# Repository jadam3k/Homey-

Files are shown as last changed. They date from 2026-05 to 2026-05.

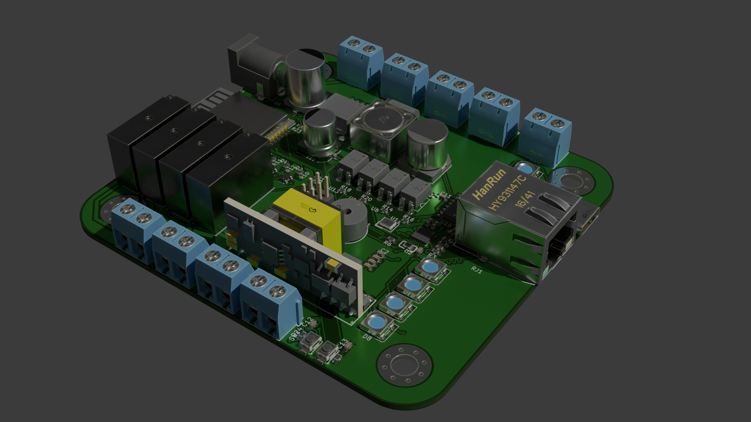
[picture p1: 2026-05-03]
Render.png

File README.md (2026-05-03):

# Homey

Homey is a compact home automation controller designed for residential use, while also being capable of operating as an industrial-style PLC for control and monitoring tasks.

The project combines Ethernet connectivity, isolated digital I/O, relay outputs, and flexible power input in a single hardware platform built around ESP32.

---

## Hardware Features

* **ESP32-based architecture** for wireless communication, local control logic, and future expansion.
* **Ethernet with PoE support** for reliable wired connectivity and simplified installation.
* **4 digital inputs** for external sensors, switches, and automation signals.
* **4 digital outputs** based on relays for switching external loads.
* **5 onboard LEDs** used for status indication, diagnostics, and visual feedback.
* **Input voltage up to 24V** for industrial and field applications.
* **5V relay section** powered separately while maintaining compatibility with higher external voltages.
* **USB-C power support** for development, testing, and low-voltage standalone operation.
* **Optocoupler isolation** allowing safe interfacing with higher voltage external circuits.

---

## Electrical Design Notes

The board is divided into functional sections.

High-voltage and switching circuitry are separated from the low-voltage logic domain in order to improve stability, reduce electrical noise, and increase operational safety.

Special attention was given to routing of high-speed and differential signals such as:

* Ethernet TX / RX
* USB D+ / D−

Component placement and routing were performed with signal integrity and practical manufacturability in mind.

---

## Firmware

The firmware has been completed and provides the basic control layer for the board.

The current software handles:

* digital input reading
* relay output control
* status LED logic
* Ethernet communication foundation

The architecture was kept clean and modular to allow future expansion for everyone - you do what you want :).

A future direction of development is communication between multiple boards using **ESP-NOW**, enabling distributed control nodes over larger areas (2/3km).

---

## Project Images

### 3D Model

Render

### Schematic



### PCB Layout / Routed Board

Zrzut ekranu 2026-05-03 140522

---

## Project Status

The project is currently considered **complete**.

Remember, if you copy it. Mention me :) i will check that.

---

## License
Just do not consider this project as your own :)

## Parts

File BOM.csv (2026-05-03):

Index | LCSC# | MPN | Manufacturer | Package | Customer # | Description | RoHS | Quantity | MOQ | Multiple | Unit Price($) | Extended Price($) | Product Link
1 | C84681 | CH340C | WCH | SOP-16 |  | Transceiver 2Mbps USB 2.0 SOP-16 Interface Controllers RoHS | yes | 2 | 1 | 1 | 0.5795 | 1.16 | https://www.lcsc.com/product-detail/C84681.html
2 | C123417 | RC0603FR-0712K1L | YAGEO | 0603 |  | 100mW 12.1kΩ 75V Thick Film Resistor ±100ppm/℃ ±1% 0603 Chip Resistor - Surface Mount RoHS | yes | 100 | 100 | 100 | 0.0017 | 0.17 | https://www.lcsc.com/product-detail/C123417.html
3 | C17181196 | B57321V2222H060 | TDK | 0603 |  | 2.2kΩ 180mW ±3% 3940K 0603 NTC Thermistors RoHS | yes | 10 | 1 | 1 | 0.0799 | 0.80 | https://www.lcsc.com/product-detail/C17181196.html
4 | C91754 | HY931147C | HANRUN(Zhongshan HanRun Elec) | Through Hole |  | Jack Modular Connector RJ45 Through Hole | yes | 2 | 1 | 1 | 2.5442 | 5.09 | https://www.lcsc.com/product-detail/C91754.html
5 | C48746 | G5NB-1A-E-DC5V | OMRON | Through Hole,20.4x7mm |  | 5V 1 Set Normally Open: 1A (SPST NO) Through Hole,20.4x7mm Power Relays RoHS | yes | 8 | 1 | 1 | 0.5668 | 4.53 | https://www.lcsc.com/product-detail/C48746.html
6 | C720477 | TS-1088-AR02016 | XUNPU | SMD,4x3mm |  | Tactile Switch SPST 160gf 2mm SMD (SMT) Tab 4mm x 3mm Surface Mount | yes | 10 | 10 | 10 | 0.0558 | 0.56 | https://www.lcsc.com/product-detail/C720477.html
7 | C701342 | ESP32-WROOM-32E-N8 | ESPRESSIF | SMD,25.5x18mm |  | 2.4GHz ESP32-DOWD-V3 On-board PCB Antenna -98dBm SMD,25.5x18mm RF Transceiver Modules and Modems RoHS | yes | 2 | 1 | 1 | 4.4175 | 8.84 | https://www.lcsc.com/product-detail/C701342.html
8 | C20612449 | PC817C | KTP | DIP-4 |  | 50mA 100mV@20mA,1mA 35V 6V 1.2V DC DIP-4 Transistor, Photovoltaic Output Optoisolators RoHS | yes | 20 | 20 | 20 | 0.0360 | 0.72 | https://www.lcsc.com/product-detail/C20612449.html
9 | C474881 | KF301-5.0-2P | Cixi Kefa Elec | Through Hole,P=5mm |  | 2 Position Wire to Board Terminal Block Through Hole 5mm | yes | 20 | 5 | 5 | 0.0919 | 1.84 | https://www.lcsc.com/product-detail/C474881.html
10 | C2907044 | FRC0603F5101TS | FOJAN | 0603 |  | 5.1kΩ ±1% 100mW 0603 Thick Film Resistor | yes | 100 | 100 | 100 | 0.0012 | 0.12 | https://www.lcsc.com/product-detail/C2907044.html
11 | C2869734 | LM66100DCKR | TI | SC-70-6 |  | 95mΩ 1 SC-70-6 OR Controllers, Ideal Diodes RoHS | yes | 10 | 5 | 5 | 0.2025 | 2.03 | https://www.lcsc.com/product-detail/C2869734.html
12 | C7471898 | 189RV0036 | KNSCHA | SMD,D10xL10.5mm |  | 680uF ±20% 35V Aluminum Electrolytic Capacitors 2000hrs@105℃ | yes | 5 | 5 | 5 | 0.2571 | 1.29 | https://www.lcsc.com/product-detail/C7471898.html
13 | C45223 | LAN8720A-CP-TR | MICROCHIP | QFN-24-EP(4x4) |  | 1.6V~3.6V PHY Transceiver RMII QFN-24-EP(4x4) Drivers, Receivers, Transceivers RoHS | yes | 2 | 1 | 1 | 0.7919 | 1.58 | https://www.lcsc.com/product-detail/C45223.html
14 | C6067465 | AMS1117-3.3 | GOODWORK | SOT-89 |  | Linear Voltage Regulator IC Positive Fixed 1 Output 1A SOT-89 | yes | 10 | 10 | 10 | 0.0442 | 0.44 | https://www.lcsc.com/product-detail/C6067465.html
15 | C5276750 | LM2596S-5.0 | TWGMC | TO-263-5 |  | 150kHz Step-down type Fixed 5V 3A TO-263-5 Voltage Regulators - DC DC Switching Regulators RoHS | yes | 2 | 1 | 1 | 0.6081 | 1.22 | https://www.lcsc.com/product-detail/C5276750.html
16 | C5380097 | DP1435-5V | SDAPO | - |  | Yes Serial Device Servers RoHS | yes | 2 | 1 | 1 | 5.0218 | 10.04 | https://www.lcsc.com/product-detail/C5380097.html
17 | C5444544 | XL2EL89COI-111YLC-25M | YXC Crystal Oscillators | SMD3225-4P |  | Crystal 25MHz ±10ppm 12pF SMD3225-4P | yes | 10 | 10 | 10 | 0.0638 | 0.64 | https://www.lcsc.com/product-detail/C5444544.html
18 | C41413840 | A254UP-ZS03P | BXCONN | Through Hole,P=2.54mm |  | Pin Header 6 Position 2.54mm Pitch Dual Row -40℃~+105℃ | yes | 20 | 20 | 20 | 0.0303 | 0.61 | https://www.lcsc.com/product-detail/C41413840.html
19 | C72519 | RVT1V471M1010 | ROQANG | SMD,D10xL10.2mm |  | 470uF ±20% 35V Aluminum Electrolytic Capacitors 2000hrs@105℃ | yes | 5 | 5 | 5 | 0.0860 | 0.43 | https://www.lcsc.com/product-detail/C72519.html
20 | C136294 | UCD1V221MNL1GS | Nichicon | SMD,D8xL10mm |  | 220uF ±20% 35V Aluminum Electrolytic Capacitors 2000hrs@105℃ | yes | 5 | 5 | 5 | 0.2894 | 1.45 | https://www.lcsc.com/product-detail/C136294.html
21 | C19702 | CL10A106KP8NNNC | Samsung Electro-Mechanics | 0603 |  | 10uF ±10% 10V Ceramic Capacitor X5R 0603 | yes | 50 | 50 | 50 | 0.0080 | 0.40 | https://www.lcsc.com/product-detail/C19702.html
22 | C22452 | SS54 | MDD(Microdiode Semiconductor) | SMA(DO-214AC) |  | Diode Independent 40V 5A Surface Mount SMA(DO-214AC) | yes | 10 | 10 | 10 | 0.0364 | 0.36 | https://www.lcsc.com/product-detail/C22452.html
23 | C5378720 | SK6812 | OPSCO Optoelectronics | SMD-4P,5.4x5mm |  | SMD-4P,5.4x5mm LED Addressable, Specialty RoHS | yes | 10 | 5 | 5 | 0.0885 | 0.89 | https://www.lcsc.com/product-detail/C5378720.html
24 | C81598 | 1N4148W | ST(Semtech) | SOD-123 |  | Diode Independent 75V 150mA Surface Mount SOD-123 | yes | 50 | 50 | 50 | 0.0112 | 0.56 | https://www.lcsc.com/product-detail/C81598.html
25 | C47345510 | 1N5822 | R+O | DO-201AD |  | Diode Independent 40V 3A Through Hole DO-201AD | yes | 5 | 5 | 5 | 0.0940 | 0.47 | https://www.lcsc.com/product-detail/C47345510.html
26 | C165948 | TYPE-C-31-M-12 | Korean Hroparts Elec | SMD |  | USB-C (USB TYPE-C) Receptacle Connector 16 Position Surface Mount | yes | 5 | 5 | 5 | 0.1702 | 0.85 | https://www.lcsc.com/product-detail/C165948.html
27 | C14663 | CC0603KRX7R9BB104 | YAGEO | 0603 |  | 100nF ±10% 50V Ceramic Capacitor X7R 0603 | yes | 100 | 100 | 100 | 0.0030 | 0.30 | https://www.lcsc.com/product-detail/C14663.html
28 | C85840 | BLM21PG221SN1D | muRata | 0805 |  | 220Ω@100MHz 1 Line Ferrite Bead 0805 2A 45mΩ | yes | 20 | 20 | 20 | 0.0398 | 0.80 | https://www.lcsc.com/product-detail/C85840.html
29 | C2929502 | CYH127-33UH | SHOU HAN | SMD,12.3x12.3mm |  | 3A 33uH ±20% 64.8mΩ SMD,12.3x12.3mm Fixed Inductors RoHS | yes | 5 | 5 | 5 | 0.3880 | 1.94 | https://www.lcsc.com/product-detail/C2929502.html
30 | C42419946 | AO3400A | ChipNobo | SOT-23 |  | 30V 5.8A 1.4W Surface Mount SOT-23 | yes | 20 | 20 | 20 | 0.0124 | 0.25 | https://www.lcsc.com/product-detail/C42419946.html
31 | C114625 | RC0603FR-0749R9L | YAGEO | 0603 |  | 100mW 49.9Ω 75V Thick Film Resistor ±100ppm/℃ ±1% 0603 Chip Resistor - Surface Mount RoHS | yes | 100 | 100 | 100 | 0.0017 | 0.17 | https://www.lcsc.com/product-detail/C114625.html
32 | C98220 | RC0603FR-0710KL | YAGEO | 0603 |  | 100mW 10kΩ 75V Thick Film Resistor ±100ppm/℃ ±1% 0603 Chip Resistor - Surface Mount RoHS | yes | 100 | 100 | 100 | 0.0015 | 0.15 | https://www.lcsc.com/product-detail/C98220.html
33 | C3000664 | FRC2512J681TS | FOJAN | 2512 |  | 1W 680Ω 200V Thick Film Resistor ±200ppm/℃ ±5% 2512 Chip Resistor - Surface Mount RoHS | yes | 50 | 50 | 50 | 0.0189 | 0.95 | https://www.lcsc.com/product-detail/C3000664.html
34 | C99782 | RC0603FR-074K7L | YAGEO | 0603 |  | 100mW 4.7kΩ 75V Thick Film Resistor ±100ppm/℃ ±1% 0603 Chip Resistor - Surface Mount RoHS | yes | 100 | 100 | 100 | 0.0015 | 0.15 | https://www.lcsc.com/product-detail/C99782.html

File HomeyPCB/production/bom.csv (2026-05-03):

Designator | Footprint | Quantity | Value | LCSC Part #
BUZZER1 | BUZ-TH_BD9.0-P4.00-D0.6-FD | 1 | QMB-09B-03 | C96256
C1, C6, C7 | 0603 | 3 | 0.22uF
C10, C3, C5 | 0603 | 3 | 1uF
C11, C12, C13, C2, C4, C9 | 0603 | 6 | 0.1uF
C14 | CAP-SMD_BD10.0-L10.3-W10.3-LS11.0-R-RD | 1 | RVT1V471M1010-C72519 | C72519
C15 | CAP-SMD_BD8.0-L8.3-W8.3-LS9.3-FD-2 | 1 | UCD1V221MNL1GS | C136294
C16, C17, C18, C8 | 0603 | 4 | 10uF
D1 | SMA_L4.4-W2.8-LS5.4-R-RD | 1 | SS54_C22452 | C22452
D10, D11, D7, D8, D9 | LED_SK6812_PLCC4_5.0x5.0mm_P3.2mm | 5 | SK6812
D2, D3, D4, D5 | SOD-123F_L2.7-W1.6-LS3.8-RD | 4 | 1N4148W_C81598 | C81598
D6 | DO-201AD_BD5.3-L8.4-P12.50-D1.4-RD | 1 | 1N5822 | C47345510
J1 | BarrelJack_Horizontal | 1 | Barrel_Jack
J6 | USB_C_Receptacle_HRO_TYPE-C-31-M-12 | 1 | USB_C_Receptacle_USB2.0_14P
J7 | PinHeader_2x03_P2.54mm_Vertical | 1 | SERVO1/2
L1 | L0805 | 1 | BLM21PG221SN1D | C85840
L2 | IND-SMD_L12.3-W12.3 | 1 | CYH127-33UH | C2929502
Q1, Q2, Q3, Q4 | SOT-23-3_L2.9-W1.3-P1.90-LS2.4-BR | 4 | AO3400A_C42419946 | C42419946
R1, R2, R3, R4 | 0603 | 4 | 49.9
R10, R11, R12, R23, R24, R25, R7, R8, R9 | 0603 | 9 | 10k
R13, R15, R17, R19 | 2512 | 4 | 680
R14, R16, R18, R20 | 0603 | 4 | 4.7k
R21, R22 | 0603 | 2 | 5.1k
R5 | 0603 | 1 | 12.1k
R6 | 0603 | 1 | 22
RJ1 | RJ45-TH_HY931147C | 1 | HY931147C | C91754
RLY1, RLY2, RLY3, RLY4 | RELAY-TH_G5NB-1A-E-DCXX | 4 | G5NB-1A-E-DC5V | C48746
SW1 | SW-SMD_L3.9-W3.0-P4.45 | 1 | BOOT | C720477
SW2 | SW-SMD_L3.9-W3.0-P4.45 | 1 | RESET | C720477
U1 | WIFI-SMD_ESP32-WROOM-32E | 1 | ESP32-WROOM-32E | C701342
U10 | CONN-TH_P5.00_KF301-5.0-2P | 1 | I2 | C474881
U11, U13, U15, U8 | DIP-4_L4.6-W6.5-P2.54-LS7.6-BL | 4 | PC817C_C20612449 | C20612449
U12 | CONN-TH_P5.00_KF301-5.0-2P | 1 | I3 | C474881
U14 | CONN-TH_P5.00_KF301-5.0-2P | 1 | I4 | C474881
U16 | SOIC-16_3.9x9.9mm_P1.27mm | 1 | CH340C
U17, U21, U23 | SC-70-6_L2.0-W1.3-P0.65-LS2.1-BL | 3 | LM66100DCKR | C2869734
U18 | CAP-SMD_BD10.0-L10.3-W10.3-LS10.8-FD | 1 | 189RV0036 | C7471898
U19 | CONN-TH_P5.00_KF301-5.0-2P | 1 | SUPPLY | C474881
U2 | QFN-24_L4.0-W4.0-P0.50-BL-EP2.6 | 1 | LAN8720A-CP-TR | C45223
U20 | SOT-89-3_L4.5-W2.5-P1.50-LS4.2-BR | 1 | AMS1117-3.3_C6067465 | C6067465
U22 | TO-263-5_L10.1-W8.7-P1.70-LS15.2-BR | 1 | LM2596S-5.0_C5276750 | C5276750
U3 | PWRM-TH_L35.6-W16.2-P2.54_DP1435-5V | 1 | DP1435-5V | C5380097
U4 | CONN-TH_P5.00_KF301-5.0-2P | 1 | 1O | C474881
U5 | CONN-TH_P5.00_KF301-5.0-2P | 1 | 2O | C474881
U6 | CONN-TH_P5.00_KF301-5.0-2P | 1 | 3O | C474881
U7 | CONN-TH_P5.00_KF301-5.0-2P | 1 | 4O | C474881
U9 | CONN-TH_P5.00_KF301-5.0-2P | 1 | I1 | C474881
X1 | CRYSTAL-SMD_4P-L3.2-W2.5-BL | 1 | X322525MOB4SI | C9006

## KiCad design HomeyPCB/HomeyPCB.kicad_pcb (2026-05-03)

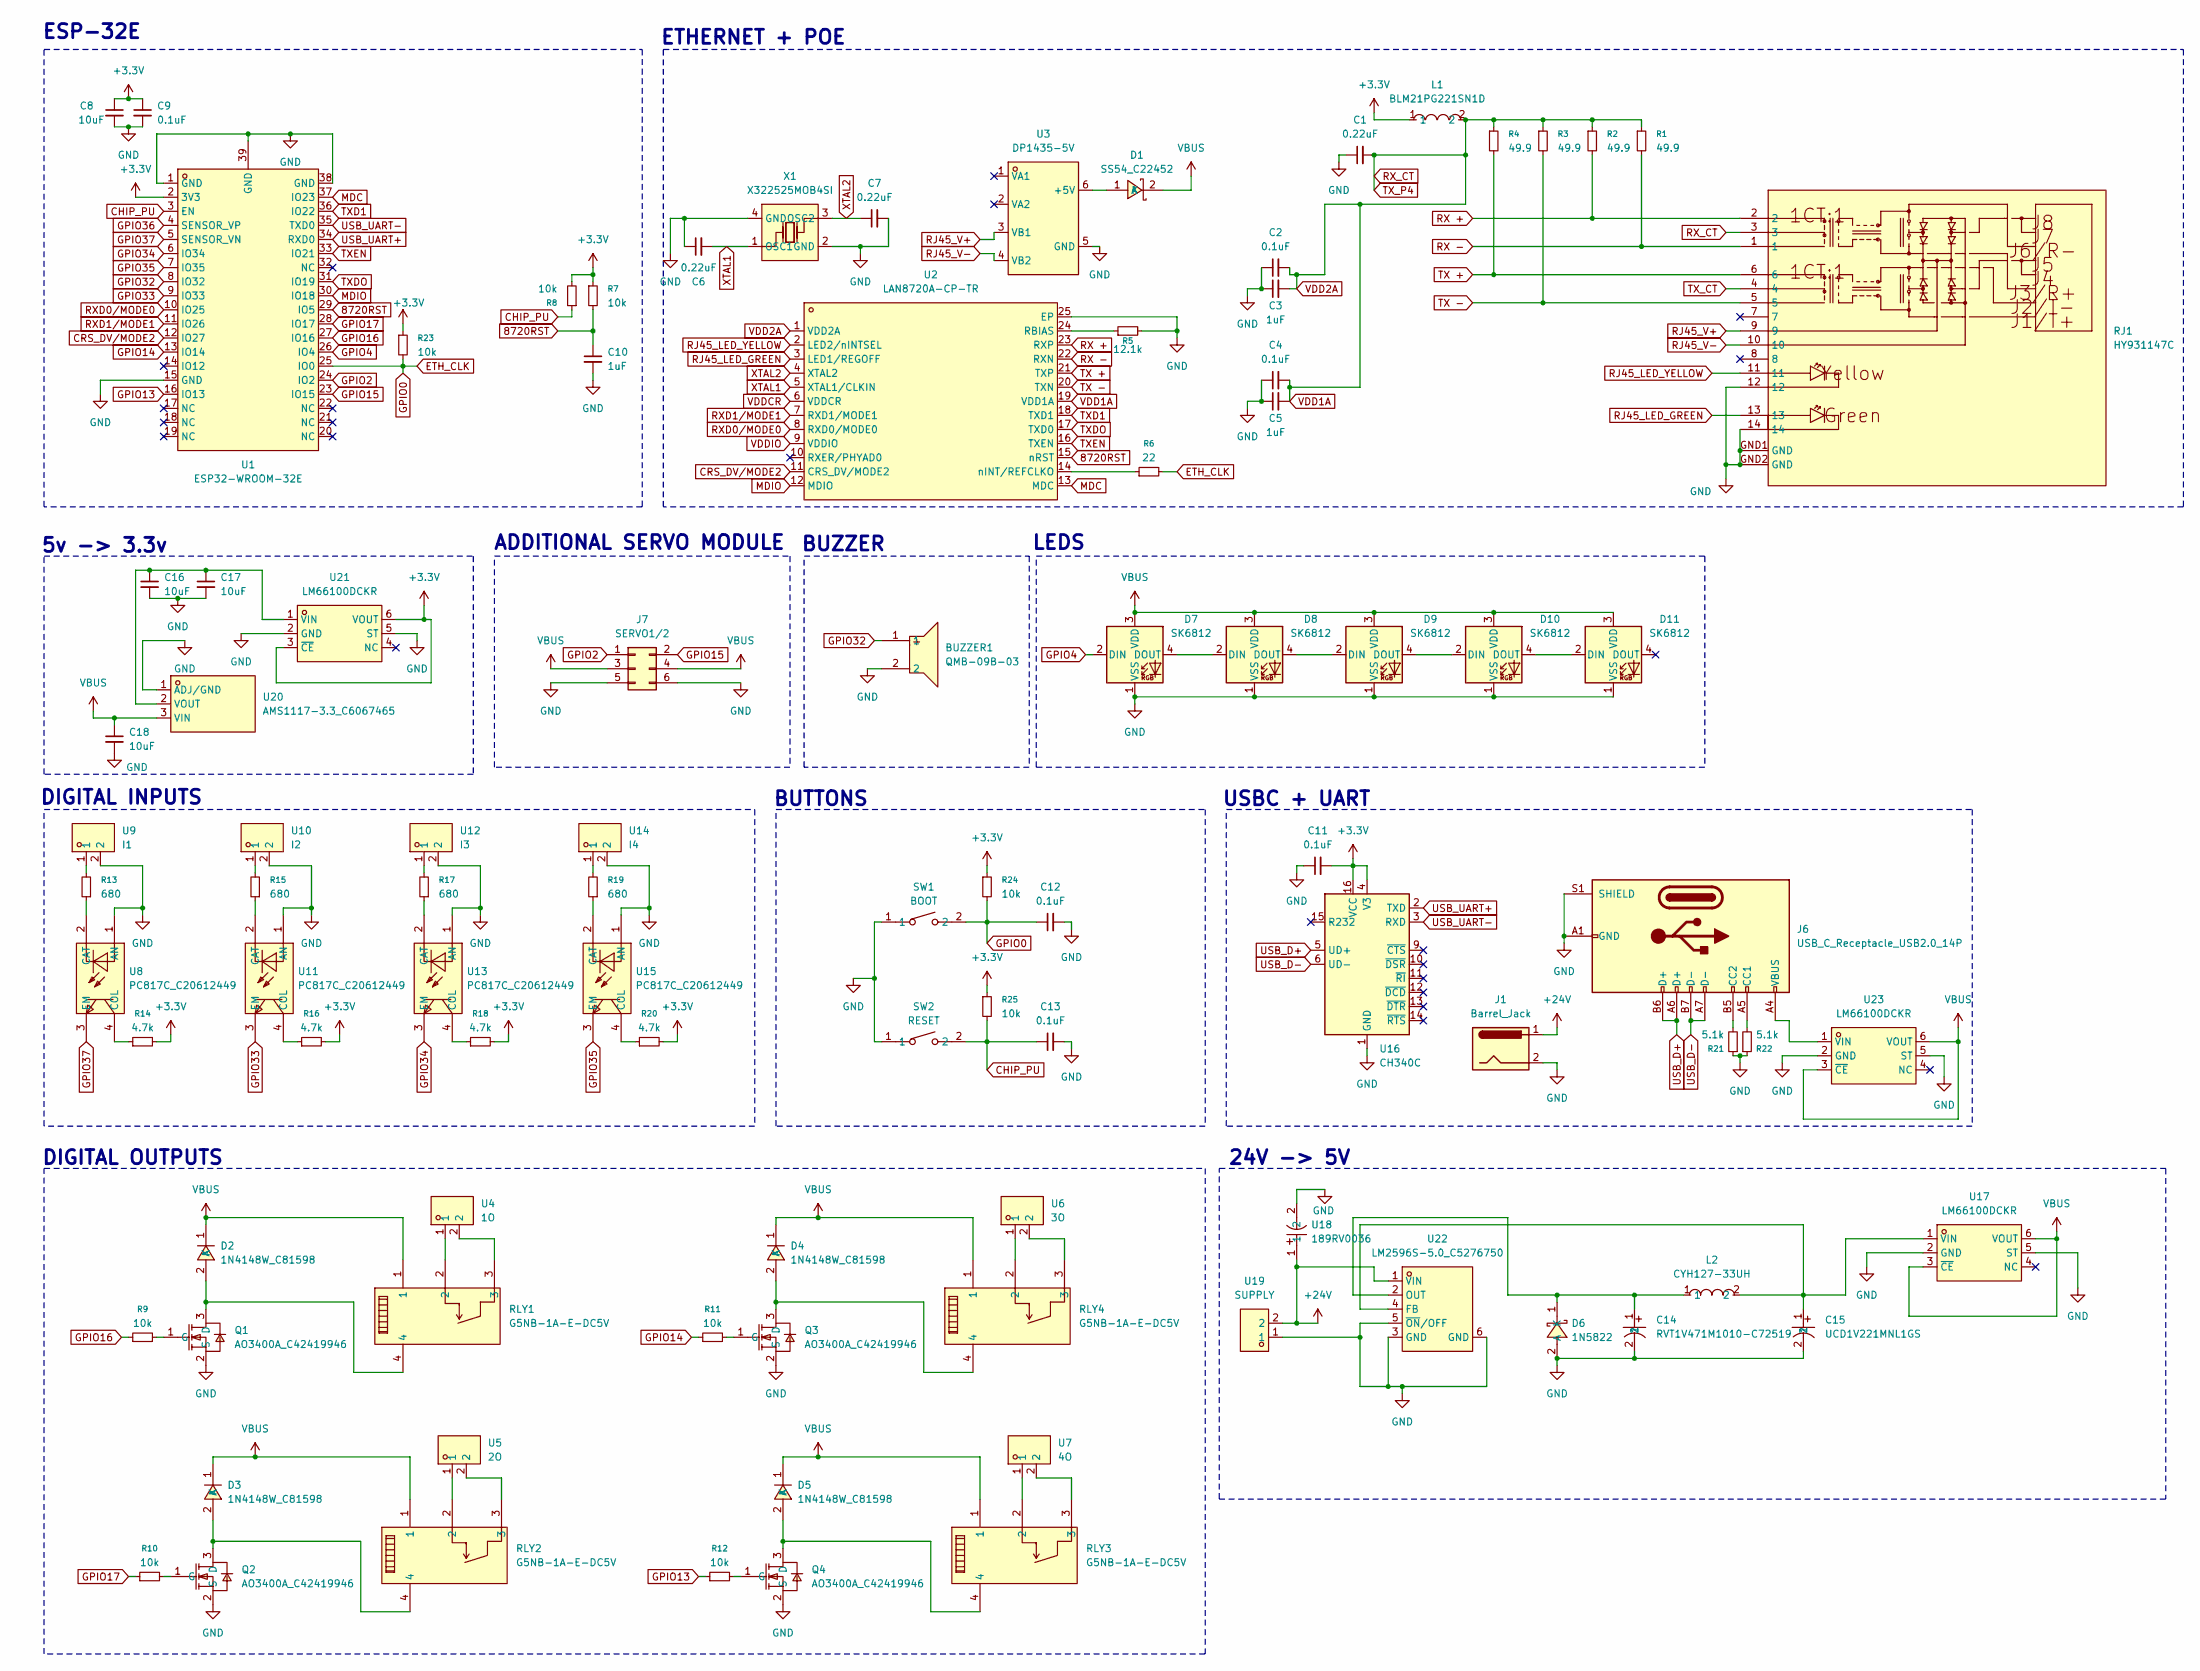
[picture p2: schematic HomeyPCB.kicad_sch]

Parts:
BUZZER1: QMB-09B-03; BUZ-TH_BD9.0-P4.00-D0.6-FD; MPN QMB-09B-03; LCSC Part C96256
C1, C6, C7: 0.22uF; C_0603_1608Metric_Pad1.08x0.95mm_HandSolder
C2, C4, C9, C11, C12, C13: 0.1uF; C_0603_1608Metric_Pad1.08x0.95mm_HandSolder
C3, C5, C10: 1uF; C_0603_1608Metric_Pad1.08x0.95mm_HandSolder
C8, C16, C17, C18: 10uF; C_0603_1608Metric_Pad1.08x0.95mm_HandSolder
C14: RVT1V471M1010-C72519; CAP-SMD_BD10.0-L10.3-W10.3-LS11.0-R-RD; MPN RVT1V471M1010; LCSC Part C72519
C15: UCD1V221MNL1GS; CAP-SMD_BD8.0-L8.3-W8.3-LS9.3-FD-2; MPN UCD1V221MNL1GS; LCSC Part C136294
D1: SS54_C22452; SMA_L4.4-W2.8-LS5.4-R-RD; MPN SS54; LCSC Part C22452
D2, D3, D4, D5: 1N4148W_C81598; SOD-123F_L2.7-W1.6-LS3.8-RD; MPN 1N4148W; LCSC Part C81598
D6: 1N5822; DO-201AD_BD5.3-L8.4-P12.50-D1.4-RD; MPN 1N5822; LCSC Part C47345510
D7, D8, D9, D10, D11: SK6812; LED_SK6812_PLCC4_5.0x5.0mm_P3.2mm
J1: Barrel_Jack; BarrelJack_Horizontal
J6: USB_C_Receptacle_USB2.0_14P; USB_C_Receptacle_HRO_TYPE-C-31-M-12
J7: SERVO1/2; PinHeader_2x03_P2.54mm_Vertical
L1: BLM21PG221SN1D; L0805; MPN BLM21PG221SN1D; LCSC Part C85840
L2: CYH127-33UH; IND-SMD_L12.3-W12.3; MPN CYH127-33UH; LCSC Part C2929502
Q1, Q2, Q3, Q4: AO3400A_C42419946; SOT-23-3_L2.9-W1.3-P1.90-LS2.4-BR; MPN AO3400A; LCSC Part C42419946
R1, R2, R3, R4: 49.9; R_0603_1608Metric_Pad0.98x0.95mm_HandSolder
R5: 12.1k; R_0603_1608Metric_Pad0.98x0.95mm_HandSolder
R6: 22; R_0603_1608Metric_Pad0.98x0.95mm_HandSolder
R7, R8, R9, R10, R11, R12, R23, R24, R25: 10k; R_0603_1608Metric_Pad0.98x0.95mm_HandSolder
R13, R15, R17, R19: 680; R_2512_6332Metric_Pad1.40x3.35mm_HandSolder
R14, R16, R18, R20: 4.7k; R_0603_1608Metric_Pad0.98x0.95mm_HandSolder
R21, R22: 5.1k; R_0603_1608Metric_Pad0.98x0.95mm_HandSolder
RJ1: HY931147C; RJ45-TH_HY931147C; MPN HY931147C; LCSC Part C91754
RLY1, RLY2, RLY3, RLY4: G5NB-1A-E-DC5V; RELAY-TH_G5NB-1A-E-DCXX; MPN G5NB-1A-E-DC5V; LCSC Part C48746
SW1: BOOT; SW-SMD_L3.9-W3.0-P4.45; MPN TS-1088-AR02016; LCSC Part C720477
SW2: RESET; SW-SMD_L3.9-W3.0-P4.45; MPN TS-1088-AR02016; LCSC Part C720477
U1: ESP32-WROOM-32E; WIFI-SMD_ESP32-WROOM-32E; MPN ESP32-WROOM-32E-N8; LCSC Part C701342
U2: LAN8720A-CP-TR; QFN-24_L4.0-W4.0-P0.50-BL-EP2.6; MPN LAN8720A-CP-TR; LCSC Part C45223
U3: DP1435-5V; PWRM-TH_L35.6-W16.2-P2.54_DP1435-5V; MPN DP1435-5V; LCSC Part C5380097
U4: 1O; CONN-TH_P5.00_KF301-5.0-2P; MPN KF301-5.0-2P; LCSC Part C474881
U5: 2O; CONN-TH_P5.00_KF301-5.0-2P; MPN KF301-5.0-2P; LCSC Part C474881
U6: 3O; CONN-TH_P5.00_KF301-5.0-2P; MPN KF301-5.0-2P; LCSC Part C474881
U7: 4O; CONN-TH_P5.00_KF301-5.0-2P; MPN KF301-5.0-2P; LCSC Part C474881
U8, U11, U13, U15: PC817C_C20612449; DIP-4_L4.6-W6.5-P2.54-LS7.6-BL; MPN PC817C; LCSC Part C20612449
U9: I1; CONN-TH_P5.00_KF301-5.0-2P; MPN KF301-5.0-2P; LCSC Part C474881
U10: I2; CONN-TH_P5.00_KF301-5.0-2P; MPN KF301-5.0-2P; LCSC Part C474881
U12: I3; CONN-TH_P5.00_KF301-5.0-2P; MPN KF301-5.0-2P; LCSC Part C474881
U14: I4; CONN-TH_P5.00_KF301-5.0-2P; MPN KF301-5.0-2P; LCSC Part C474881
U16: CH340C; SOIC-16_3.9x9.9mm_P1.27mm
U17, U21, U23: LM66100DCKR; SC-70-6_L2.0-W1.3-P0.65-LS2.1-BL; MPN LM66100DCKR; LCSC Part C2869734
U18: 189RV0036; CAP-SMD_BD10.0-L10.3-W10.3-LS10.8-FD; MPN 189RV0036; LCSC Part C7471898
U19: SUPPLY; CONN-TH_P5.00_KF301-5.0-2P; MPN KF301-5.0-2P; LCSC Part C474881
U20: AMS1117-3.3_C6067465; SOT-89-3_L4.5-W2.5-P1.50-LS4.2-BR; MPN AMS1117-3.3; LCSC Part C6067465
U22: LM2596S-5.0_C5276750; TO-263-5_L10.1-W8.7-P1.70-LS15.2-BR; MPN LM2596S-5.0; LCSC Part C5276750
X1: X322525MOB4SI; CRYSTAL-SMD_4P-L3.2-W2.5-BL; MPN X322525MOB4SI; LCSC Part C9006

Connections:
8720RST: C10.1, R7.2, U1.29 (IO5), U2.15 (nRST)
+3.3V: C8.1, C9.1, C11.2, L1.1, R7.1, R8.2, R14.2, R16.2, R18.2, R20.2, R23.1, R24.1, R25.1, U1.2 (3V3), U16.4 (V3), U16.16 (VCC), U21.3 (~CE), U21.6 (VOUT)
+24V: J1.1, U18.1, U19.2, U22.1 (VIN)
CHIP_PU: C13.1, R8.1, R25.2, SW2.2, U1.3 (EN)
CRS_DV/MODE2: U1.12 (IO27), U2.11 (CRS_DV/MODE2)
ETH_CLK: C12.1, R6.2, R23.2, R24.2, SW1.2, U1.25 (IO0)
GND: BUZZER1.2, C1.1, C2.1, C3.1, C4.1, C5.1, C6.1, C7.2, C8.2, C9.2, C10.2, C11.1, C12.2, C13.2, C14.2, C15.2, C16.2, C17.2, C18.2, D6.2 (A), D7.1 (VSS), D8.1 (VSS), D9.1 (VSS), D10.1 (VSS), D11.1 (VSS), J1.2, J6.A1 (GND), J6.A12 (GND), J6.B1 (GND), J6.B12 (GND), J6.S1 (SHIELD), J7.5, J7.6, Q1.2 (S), Q2.2 (S), Q3.2 (S), Q4.2 (S), R5.2, R21.1, R22.1, RJ1.12, RJ1.14, RJ1.GND1 (GND), RJ1.GND2 (GND), SW1.1, SW2.1, U1.1 (GND), U1.15 (GND), U1.38 (GND), U1.39 (GND), U2.25 (EP), U3.5 (GND), U8.1 (AN), U9.2, U10.2, U11.1 (AN), U12.2, U13.1 (AN), U14.2, U15.1 (AN), U16.1 (GND), U17.2 (GND), U17.5 (ST), U18.2, U19.1, U20.1 (ADJ/GND), U21.2 (GND), U21.5 (ST), U22.3 (GND), U22.5 (~ON/OFF), U22.6 (GND), U23.2 (GND), U23.5 (ST), X1.2 (GND), X1.4 (GND)
GPIO2: J7.1, U1.24 (IO2)
GPIO4: D7.2 (DIN), U1.26 (IO4)
GPIO13: R12.1, U1.16 (IO13)
GPIO14: R11.1, U1.13 (IO14)
GPIO15: J7.2, U1.23 (IO15)
GPIO16: R9.1, U1.27 (IO16)
GPIO17: R10.1, U1.28 (IO17)
GPIO32: BUZZER1.1, U1.8 (IO32)
GPIO33: U1.9 (IO33), U11.3 (EM)
GPIO34: U1.6 (IO34), U13.3 (EM)
GPIO35: U1.7 (IO35), U15.3 (EM)
GPIO36: U1.4 (SENSOR_VP)
GPIO37: U1.5 (SENSOR_VN), U8.3 (EM)
MDC: U1.37 (IO23), U2.13 (MDC)
MDIO: U1.30 (IO18), U2.12 (MDIO)
unnamed: D1.1 (A), U3.6 (+5V)
unnamed: D2.2 (A), Q1.3 (D), RLY1.4
unnamed: D3.2 (A), Q2.3 (D), RLY2.4
unnamed: D4.2 (A), Q3.3 (D), RLY4.4
unnamed: D5.2 (A), Q4.3 (D), RLY3.4
unnamed: C14.1, D6.1 (K), L2.1, U22.2 (OUT)
unnamed: D7.4 (DOUT), D8.2 (DIN)
unnamed: D8.4 (DOUT), D9.2 (DIN)
unnamed: D9.4 (DOUT), D10.2 (DIN)
unnamed: D10.4 (DOUT), D11.2 (DIN)
unnamed: J6.A5 (CC1), R22.2
unnamed: J6.B5 (CC2), R21.2
unnamed: Q1.1 (G), R9.2
unnamed: Q2.1 (G), R10.2
unnamed: Q3.1 (G), R11.2
unnamed: Q4.1 (G), R12.2
unnamed: R13.2, U9.1
unnamed: R15.2, U10.1
unnamed: R17.2, U12.1
unnamed: R19.2, U14.1
unnamed: RLY1.2, U4.1
unnamed: RLY1.3, U4.2
unnamed: RLY2.2, U5.1
unnamed: RLY2.3, U5.2
unnamed: RLY3.2, U7.1
unnamed: RLY3.3, U7.2
unnamed: RLY4.2, U6.1
unnamed: RLY4.3, U6.2
unnamed: R5.1, U2.24 (RBIAS)
unnamed: R6.1, U2.14 (nINT/REFCLKO)
unnamed: R13.1, U8.2 (CAT)
unnamed: R14.1, U8.4 (COL)
unnamed: R15.1, U11.2 (CAT)
unnamed: R16.1, U11.4 (COL)
unnamed: R17.1, U13.2 (CAT)
unnamed: R18.1, U13.4 (COL)
unnamed: R19.1, U15.2 (CAT)
unnamed: R20.1, U15.4 (COL)
unnamed: C15.1, L2.2, U17.1 (VIN), U22.4 (FB)
unnamed: C16.1, C17.1, U20.2 (VOUT), U21.1 (VIN)
unnamed: J6.A4 (VBUS), J6.A9 (VBUS), J6.B4 (VBUS), J6.B9 (VBUS), U23.1 (VIN)
RJ45_LED_GREEN: RJ1.13, U2.3 (LED1/REGOFF)
RJ45_LED_YELLOW: RJ1.11, U2.2 (LED2/nINTSEL)
RJ45_V+: RJ1.9, U3.3 (VB1)
RJ45_V-: RJ1.10, U3.4 (VB2)
RX +: R2.2, RJ1.2, U2.23 (RXP)
RX -: R1.2, RJ1.1, U2.22 (RXN)
RXD0/MODE0: U1.10 (IO25), U2.8 (RXD0/MODE0)
RXD1/MODE1: U1.11 (IO26), U2.7 (RXD1/MODE1)
RX_CT: C1.2, C2.2, C3.2, C4.2, C5.2, L1.2, R1.1, R2.1, R3.1, R4.1, RJ1.3, U2.1 (VDD2A), U2.19 (VDD1A)
TX +: R4.2, RJ1.6, U2.21 (TXP)
TX -: R3.2, RJ1.5, U2.20 (TXN)
TXD1: U1.36 (IO22), U2.18 (TXD1)
TXDO: U1.31 (IO19), U2.17 (TXD0)
TXEN: U1.33 (IO21), U2.16 (TXEN)
TX_CT: RJ1.4
USB_D+: J6.A6 (D+), J6.B6 (D+), U16.5 (UD+)
USB_D-: J6.A7 (D-), J6.B7 (D-), U16.6 (UD-)
USB_UART+: U1.34 (RXD0), U16.2 (TXD)
USB_UART-: U1.35 (TXD0), U16.3 (RXD)
VBUS: C18.1, D1.2 (K), D2.1 (K), D3.1 (K), D4.1 (K), D5.1 (K), D7.3 (VDD), D8.3 (VDD), D9.3 (VDD), D10.3 (VDD), D11.3 (VDD), J7.3, J7.4, RLY1.1, RLY2.1, RLY3.1, RLY4.1, U17.3 (~CE), U17.6 (VOUT), U20.3 (VIN), U23.3 (~CE), U23.6 (VOUT)
VDDCR: U2.6 (VDDCR)
VDDIO: U2.9 (VDDIO)
XTAL1: C6.2, U2.5 (XTAL1/CLKIN), X1.1 (OSC1)
XTAL2: C7.1, U2.4 (XTAL2), X1.3 (OSC2)

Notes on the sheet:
ESP-32E
USBC + UART
ETHERNET + POE
5v -> 3.3v
BUTTONS
LEDS
DIGITAL INPUTS
BUZZER
ADDITIONAL SERVO MODULE
24V -> 5V
DIGITAL OUTPUTS

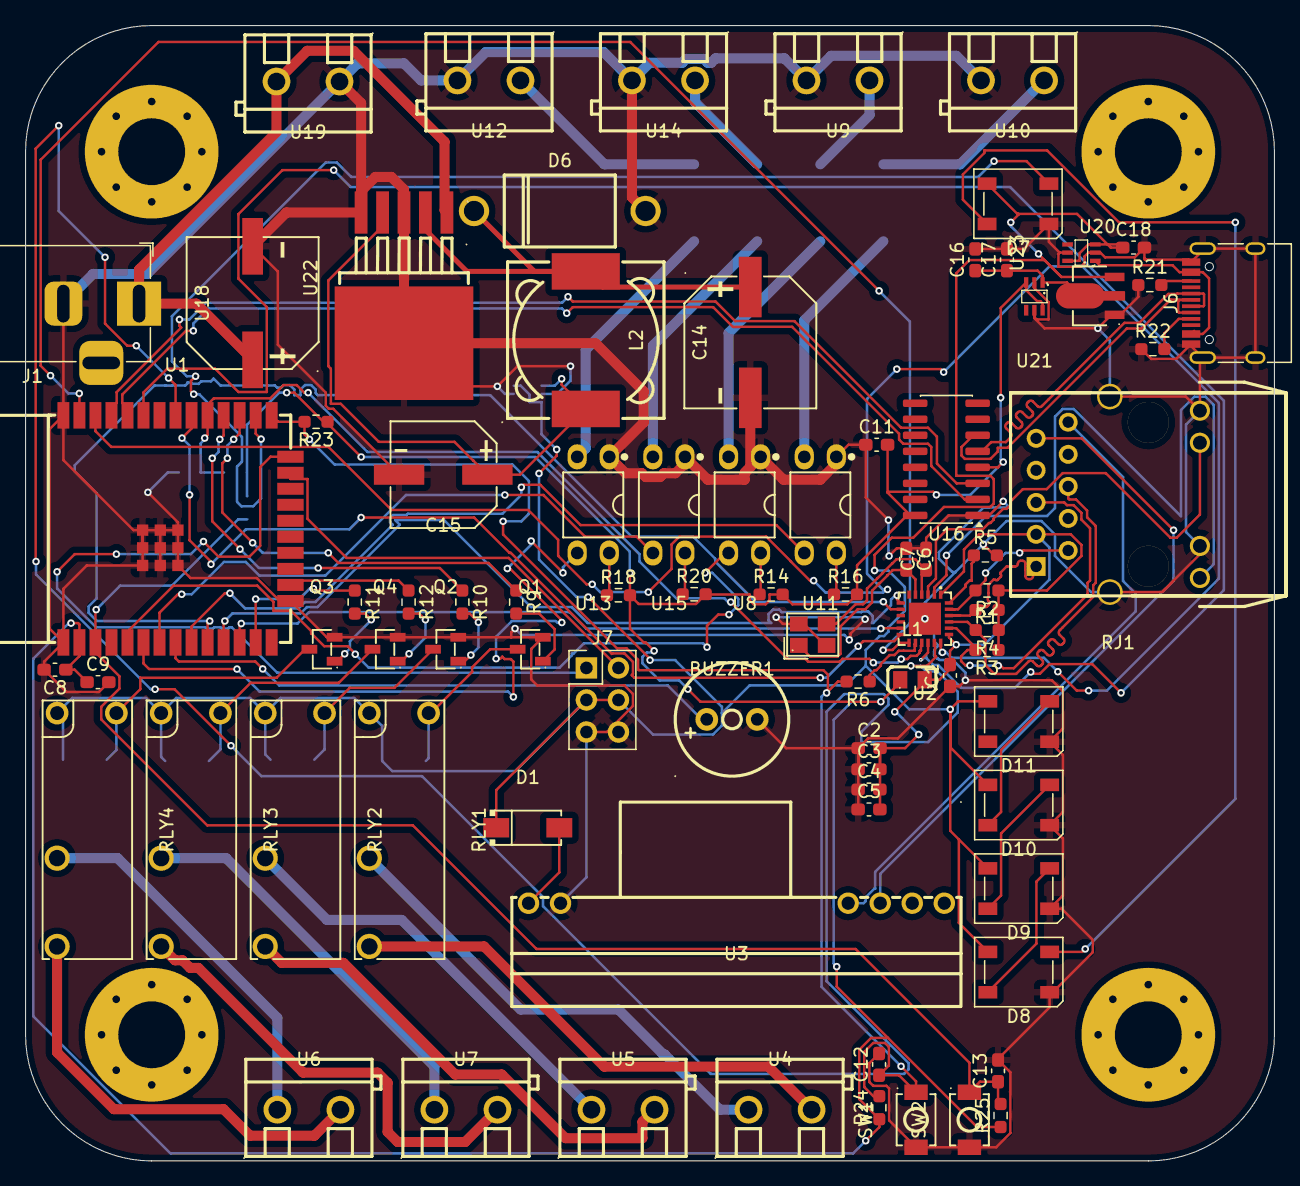
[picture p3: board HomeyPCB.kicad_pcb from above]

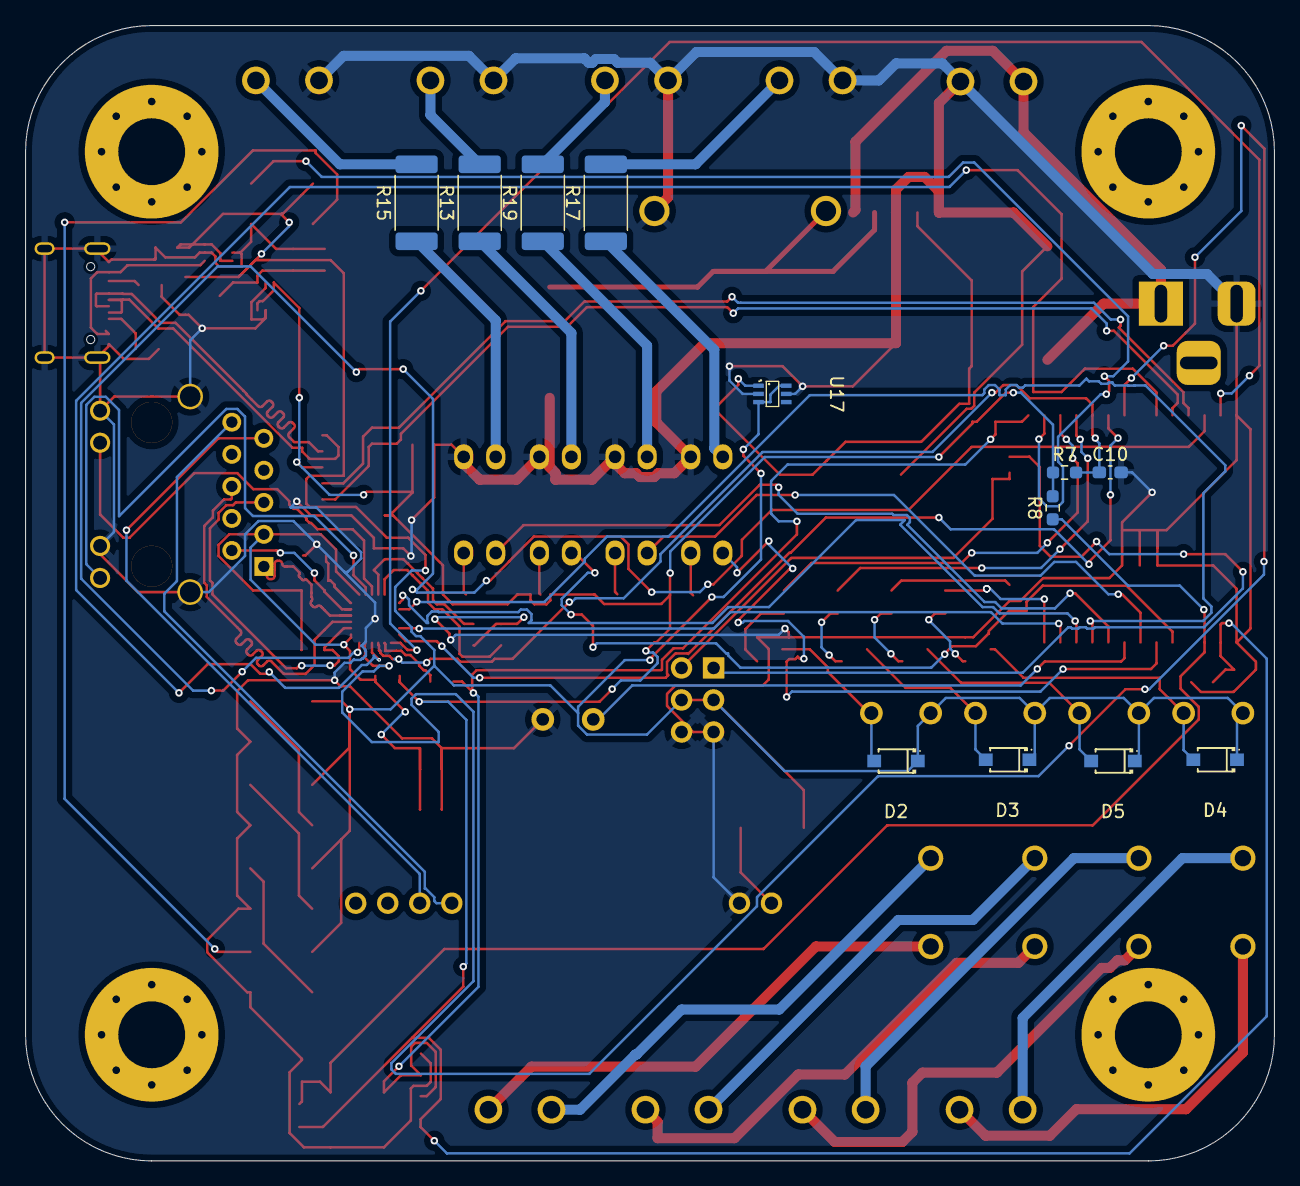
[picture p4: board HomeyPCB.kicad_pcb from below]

Board: 2 copper layers, 99.0 x 90.0 mm, 95 parts (12 on the bottom side), 83 nets.

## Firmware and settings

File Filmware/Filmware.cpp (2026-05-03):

#include <ETH.h>
#include <Adafruit_NeoPixel.h>
#include <ESP32Servo.h>

#define ETH_ADDR          0
#define ETH_POWER_PIN    -1 
#define ETH_MDC_PIN       23
#define ETH_MDIO_PIN      18
#define ETH_TYPE          ETH_PHY_LAN8720
#define ETH_CLK_MODE      ETH_CLOCK_GPIO0_IN

const int relays[] = {16, 17, 14, 13};
const int inputs[] = {33, 37, 34, 35};

#define PIN_SERVO1 2
#define PIN_SERVO2 15
#define PIN_BUZZER 32
#define PIN_LED    4

Adafruit_NeoPixel strip(1, PIN_LED, NEO_GRB + NEO_KHZ800);
Servo s1, s2;

void WiFiEvent(WiFiEvent_t event) {
  switch (event) {
    case ARDUINO_EVENT_ETH_GOT_IP:
      Serial.println(ETH.localIP());
      break;
    default: break;
  }
}

void setup() {
  Serial.begin(115200);

  WiFi.onEvent(WiFiEvent);
  ETH.begin(ETH_ADDR, ETH_POWER_PIN, ETH_MDC_PIN, ETH_MDIO_PIN, ETH_TYPE, ETH_CLK_MODE);

  for(int i=0; i<4; i++) {
    pinMode(relays[i], OUTPUT);
    digitalWrite(relays[i], LOW);
  }

  for(int i=0; i<4; i++) {
    pinMode(inputs[i], INPUT);
  }

  pinMode(PIN_BUZZER, OUTPUT);
  s1.attach(PIN_SERVO1);
  s2.attach(PIN_SERVO2);

  strip.begin();
  strip.show();
}

void loop() {
  if (digitalRead(37) == LOW) {
    digitalWrite(16, HIGH);
  } else {
    digitalWrite(16, LOW);
  }
  delay(50);
}
